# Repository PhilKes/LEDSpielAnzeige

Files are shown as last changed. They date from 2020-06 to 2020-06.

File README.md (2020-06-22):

# LEDSpielAnzeige - Controller for LED Scoreboard
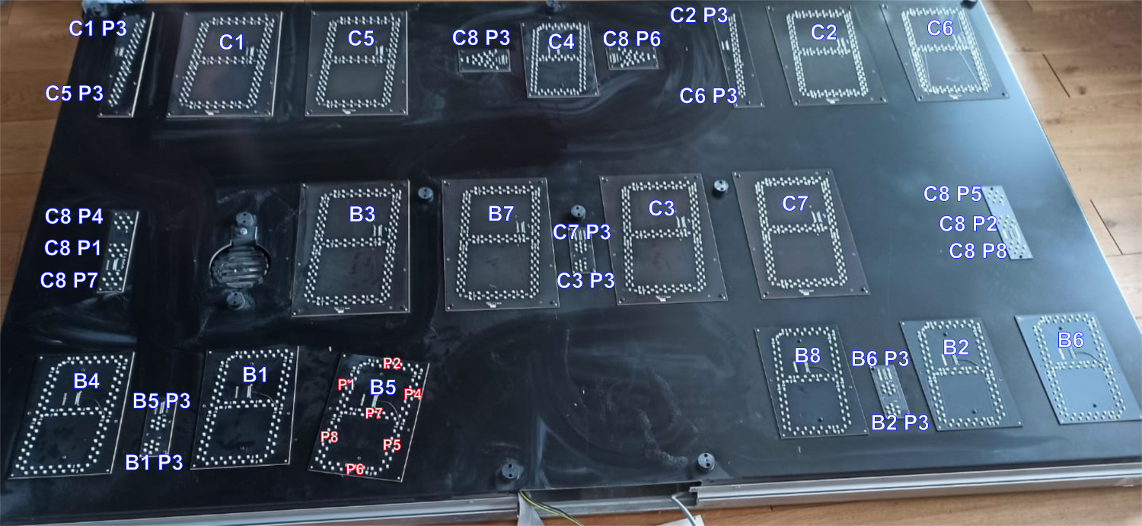
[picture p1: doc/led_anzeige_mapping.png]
LED Display
 
 
 ### Display
 * 2 x 8 7-Segment Displays
 * Eacg Segment 7 LEDs in Series (Vfor=1.9V)
 * Center Segments 8 LEDs in Series
 * All Anodes (+) of the same Segments connected (all SegA,...) (Data)
 * LEDs of a single 7-Segment Display have a common Cathode (-) (Address)
 * DecimalPoint connections for ":",">","|",...
 
 ### Connections
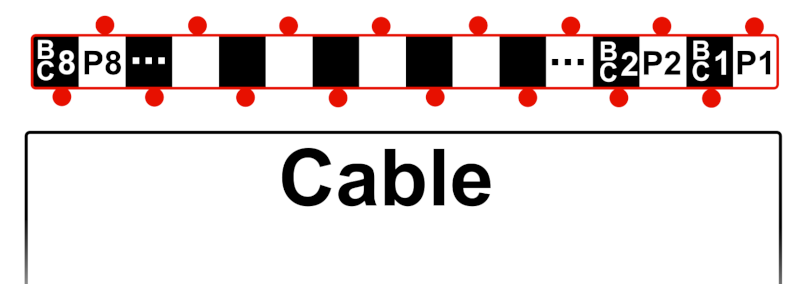
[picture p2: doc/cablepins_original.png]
2x8 Cable Pinout
  
 * 2x 16Pin Cable connections
 * 8 Pin Address (only a single Bit "1" at a time)
 * 8 Pin Data (7-Segments)
 * Addresses are multiplexed
 
 ### Schematic
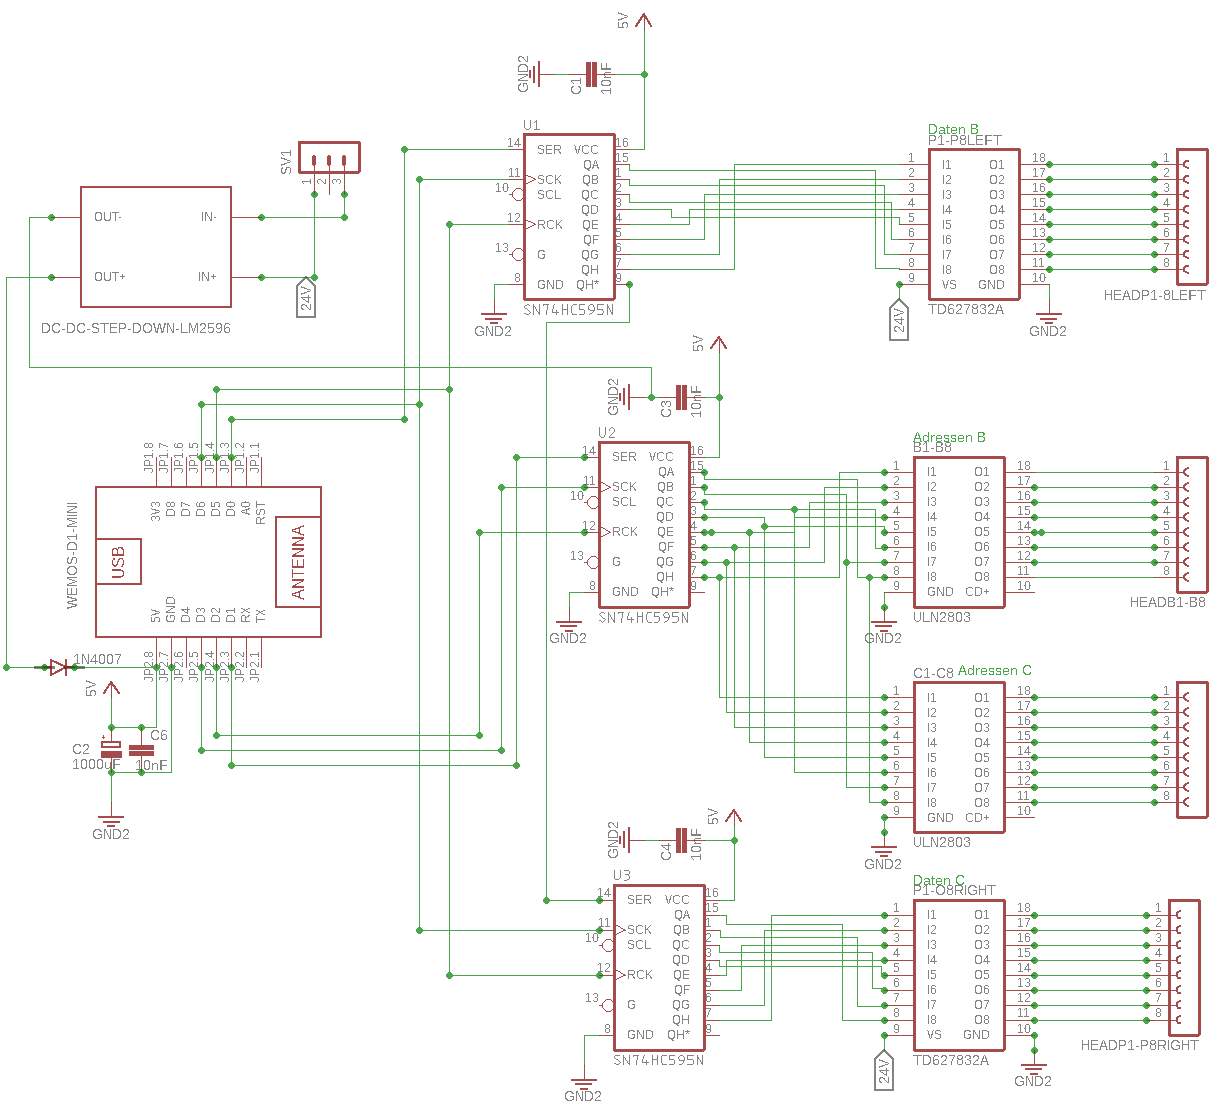
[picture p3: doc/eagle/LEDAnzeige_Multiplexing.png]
Display_Schaltplan
 
  ---
 ### Board
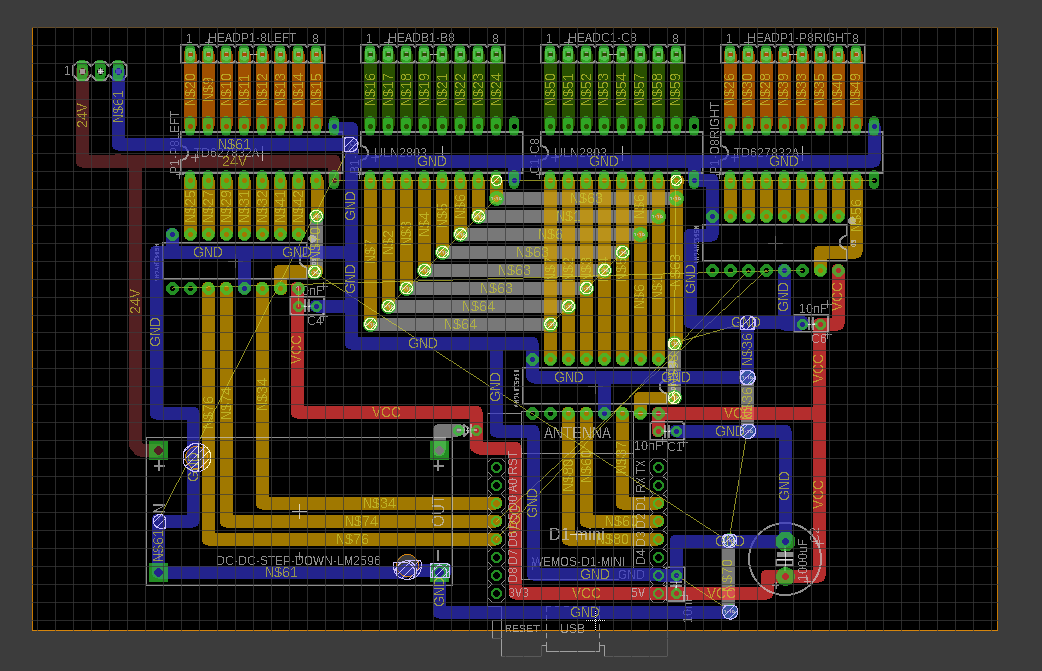
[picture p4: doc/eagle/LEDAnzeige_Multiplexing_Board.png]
Display_Board
 
 [Mirrored Image for Soldering](./doc/eagle/LEDAnzeige_Multiplexing_Board_mirror.png)
 ---
 #### Parts
  * [LM2596 Step-Down DC Buck Converter](https://www.reichelt.de/schaltregler-step-down-adj-3a-4-75-40vi-to220-5-lm2596tvadj-p255435.html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)
  * [IC Sockel 14/16pin](https://www.reichelt.de/ic-sockel-16-polig-doppelter-federkontakt-gs-16-p8208.html?&nbc=1)
  * [Perboard 16x10cm](https://www.reichelt.de/lochrasterplatine-hartpapier-160x100mm-h25pr160-p8272.html?&nbc=1)
  * [WeMos D1 mini](https://www.ebay.de/itm/D1Mini-ESP8266-Modul-Mikrokontroller-Board-WLAN-Wifi-Nodemcu-Wemos-Arduino/164007576934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)
  * [DCAdapter 24V](https://www.reichelt.de/steckernetzteil-25-w-24-v-1-04-a-mw-gst25e24-p171101.html?&nbc=1)
#### Drivers
 * [UDN 2981(=_TD62783AP_)  Source Driver](https://www.reichelt.de/leistungstreiber-8-kanal-dil-18-udn-2981-p22008.html?&trstct=pos_0&nbc=1)
 * [ULN2803 NPN Darlington Arrays](https://www.reichelt.de/eight-darlington-arrays-dil-18-uln-2803a-p22085.html?&trstct=pos_0&nbc=1)
 * [74HC595 Shift Register](https://www.reichelt.de/shift-register-3-state-ausgang-2-6-v-dil-16-74hc-595-p3269.html?&trstct=pos_0&nbc=1)
 ---
 
 # Code
 
 ### Wemos Arduino Sketch
 * **Multiplexing** both Addressbusses (**Common Cathodes**) (_ULN2803s_ "B1-B8"+"C1-C8") with 1x _74HC595_ ("U2") output
 * Loading **7-Segment Data** (**Anodes**) for every Display concurrent to multiplexing with 2x _74HC595_ ("U1"+"U3")
 * Switch modes on **WiFi** commands
 
 ### React Web App
 * **WebServer** for User Interface
 * Sending Commands over WiFi
 * [ESP8266-React Framework](https://github.com/rjwats/esp8266-react)
 ---
 ### Links
 * [ULN2803 Function](https://www.conrad.de/de/ratgeber/handwerk-industrie-wiki/elektronik-bauteile/uln2803.html#anschluss)
 * [Arduino Forum Thread](https://forum.arduino.cc/index.php?topic=688158.0)

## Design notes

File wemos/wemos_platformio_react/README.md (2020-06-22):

# Wemos_react_platformio

## Getting Started
 #### Settings
 1. Make sure in [/factory_settings](./factory_settings.ini) WiFi Access Point is enabled:
`-D FACTORY_AP_PROVISION_MODE=AP_MODE_ALWAYS`
 2. [Build & Upload](#building--uploading) the Project
 3. Connect to *ESP8266-React* WiFi network via Phone

#### WiFi
 1. WiFi Connection-> Scan Networks -> Connect to local WiFi
 2. Preferably set a Static IP for Local Development (see [.env.development](./interface/.env.development))

 #### NTP
1. Network Time -> NTP Settings
2. Select correct Time Zone -> Save
 
### Building & Uploading
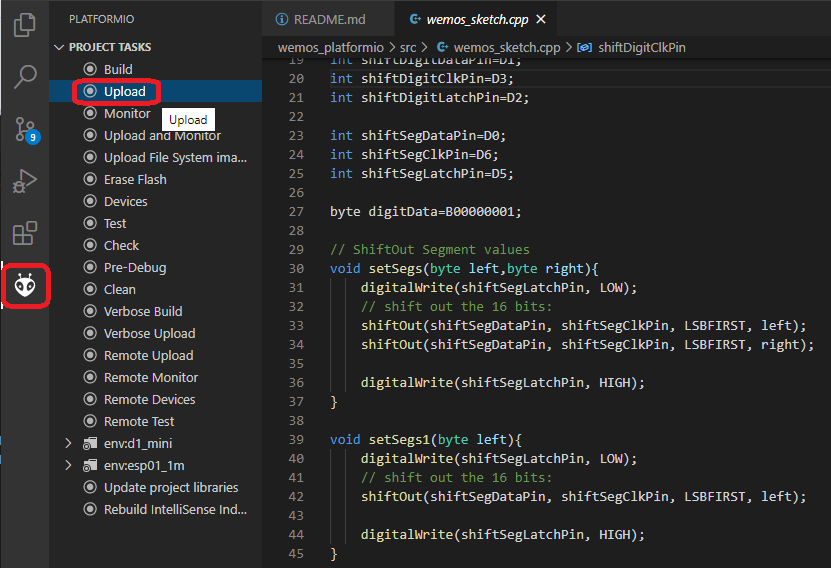
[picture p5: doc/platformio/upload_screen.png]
Build+Upload


To Enable/Disable OTA Upload [platformio.ini](./platformio.ini)):

`; Uncomment & modify the lines below in order to configure OTA updates
;upload_protocol=espota
;upload_port = 192.168.178.55
;upload_auth=esp-react`

#### Debugging
in [main.cpp](./src/main.cpp) and [wemos_sketch.h](./src/wemos/wemos_sketch.h):

`#define DEBUG true`

to enable Debugging via Serial-Connection (USB + `Serial.print`)

Default Environment: d1_mini

# Code
## Wemos Backend Sketch
[main.cpp](./src/main.cpp)

Runs ESP8266 React Web Server + Wemos Sketch Loop

[wemos_sketch.h](./src/wemos_sketch.h):

`wemosLoop(digitsLeft,digitsRight,ntpStatus)`

* Executes Multiplex with current digits as Segment Values (`digitsLeft` & `digitsRight` changed by HTTP Requests from WebServer)
* `ntpStatus` can be used to get current Time (`setTime(ntpStatus->getTime())`)

[LEDScoreboardService](./src/LEDScoreboardService.h)

* Receives state (`digitsLeft` & `digitsRight`) updates from frontend HTTP requests via ArduinoJson Objects
* Accesses `NTPStatus` to get current LocalTime

---

## Wemos React Frontend App

[LEDScoreboardRestController.tsx](./interface/src/project/LEDScoreboardRestController.tsx)

Subpage for sending HTTP Requests to control `digitsLeft` & `digitsRight`

`LEDScoreboardRestControllerForm` (React component for Inputs to change digit Values / modes)

Given component `props`:
* `data` : corresponds to [LEDScoreboardState in backend](./src/LEDScoreboardService.h)
* `loadData()` : Fetches state from backend
* `handleValueChange(String propertyKey)` : Sets value of given property
* `saveData()` : Sends updated state to backend

---

#### Libraries Used

* [React](https://reactjs.org/)
* [Material-UI](https://material-ui.com/)
* [notistack](https://github.com/iamhosseindhv/notistack)
* [ArduinoJson](https://github.com/bblanchon/ArduinoJson)
* [ESPAsyncWebServer](https://github.com/me-no-dev/ESPAsyncWebServer)
* [AsyncMqttClient](https://github.com/marvinroger/async-mqtt-client)

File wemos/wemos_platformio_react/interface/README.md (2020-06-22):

# LED Scoreboard - ESP8266 React

[Main Project Page .tsx](./src/project/LEDScoreboard)

## LED Scoreboard Project Routes:
_LEDScoreboard.tsx_:

    <Switch>
      <AuthenticatedRoute exact path={`/${PROJECT_PATH}/rest`} component={LightStateRestController} />
      <AuthenticatedRoute exact path={`/${PROJECT_PATH}/socket`} component={LightStateWebSocketController} />
      <Redirect to={`/${PROJECT_PATH}/rest`} />
    </Switch>

## REST Controller
HTTP Request to control WeMos

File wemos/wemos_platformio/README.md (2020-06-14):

## Wemos PlatformIO Project

### Code

Main Code in [/src/wemos_sketch.cpp](./src/wemos_sketch.cpp)

Different Modes/Animations in [/src/modes.h](./src/modes.h)

### Building & Uploading
Build+Upload

Default Environment: d1_mini (see [platformio.ini](./platformio.ini))

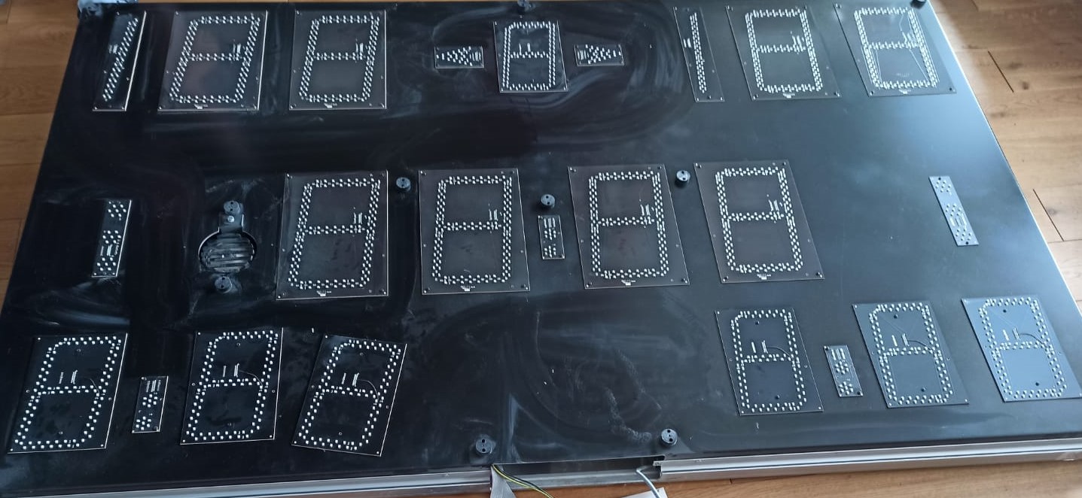
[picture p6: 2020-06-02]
doc/led_anzeige_bild.jpg

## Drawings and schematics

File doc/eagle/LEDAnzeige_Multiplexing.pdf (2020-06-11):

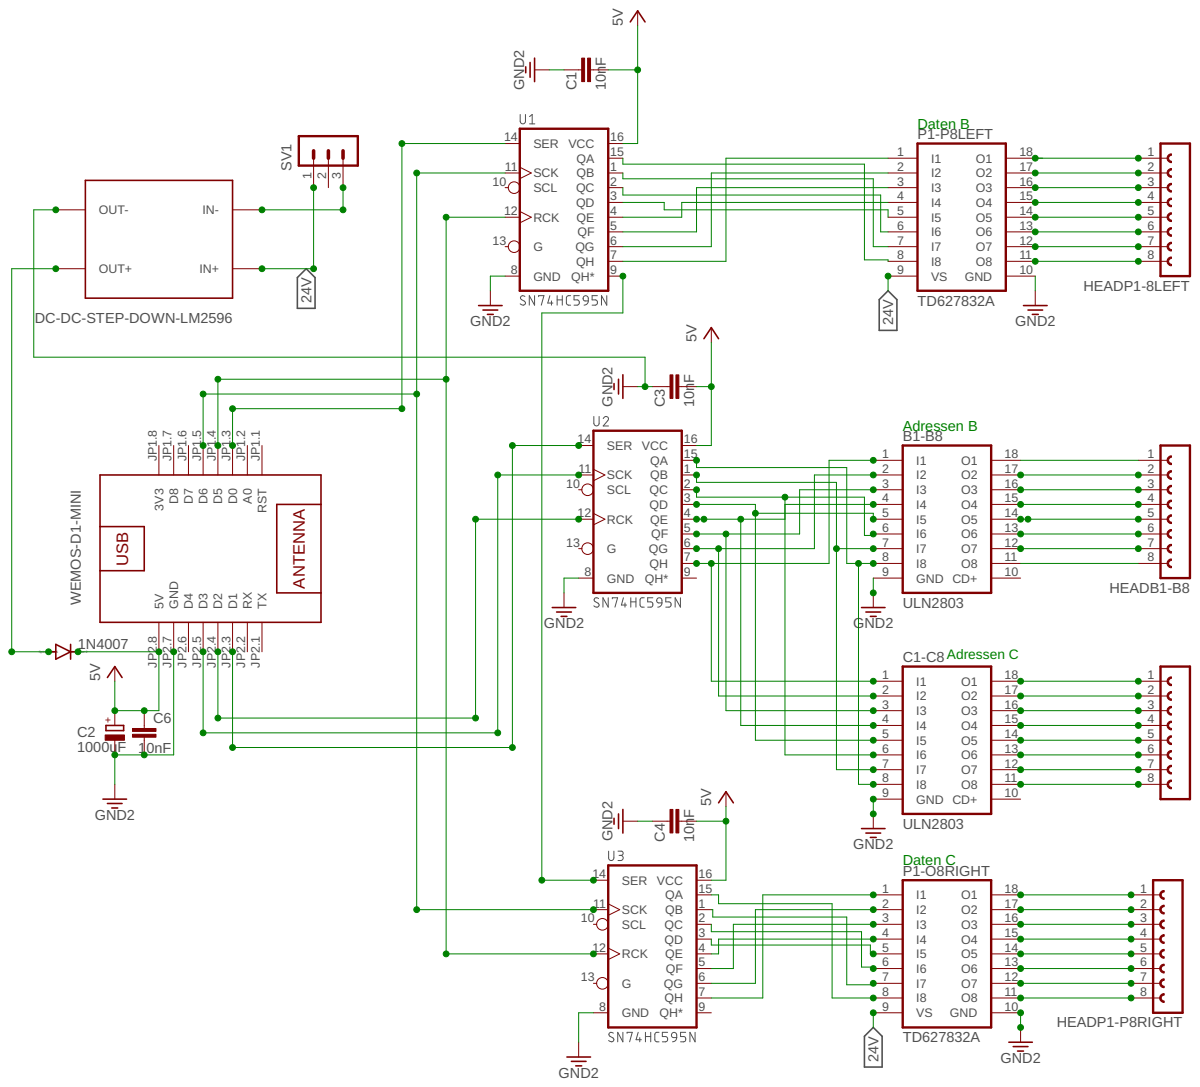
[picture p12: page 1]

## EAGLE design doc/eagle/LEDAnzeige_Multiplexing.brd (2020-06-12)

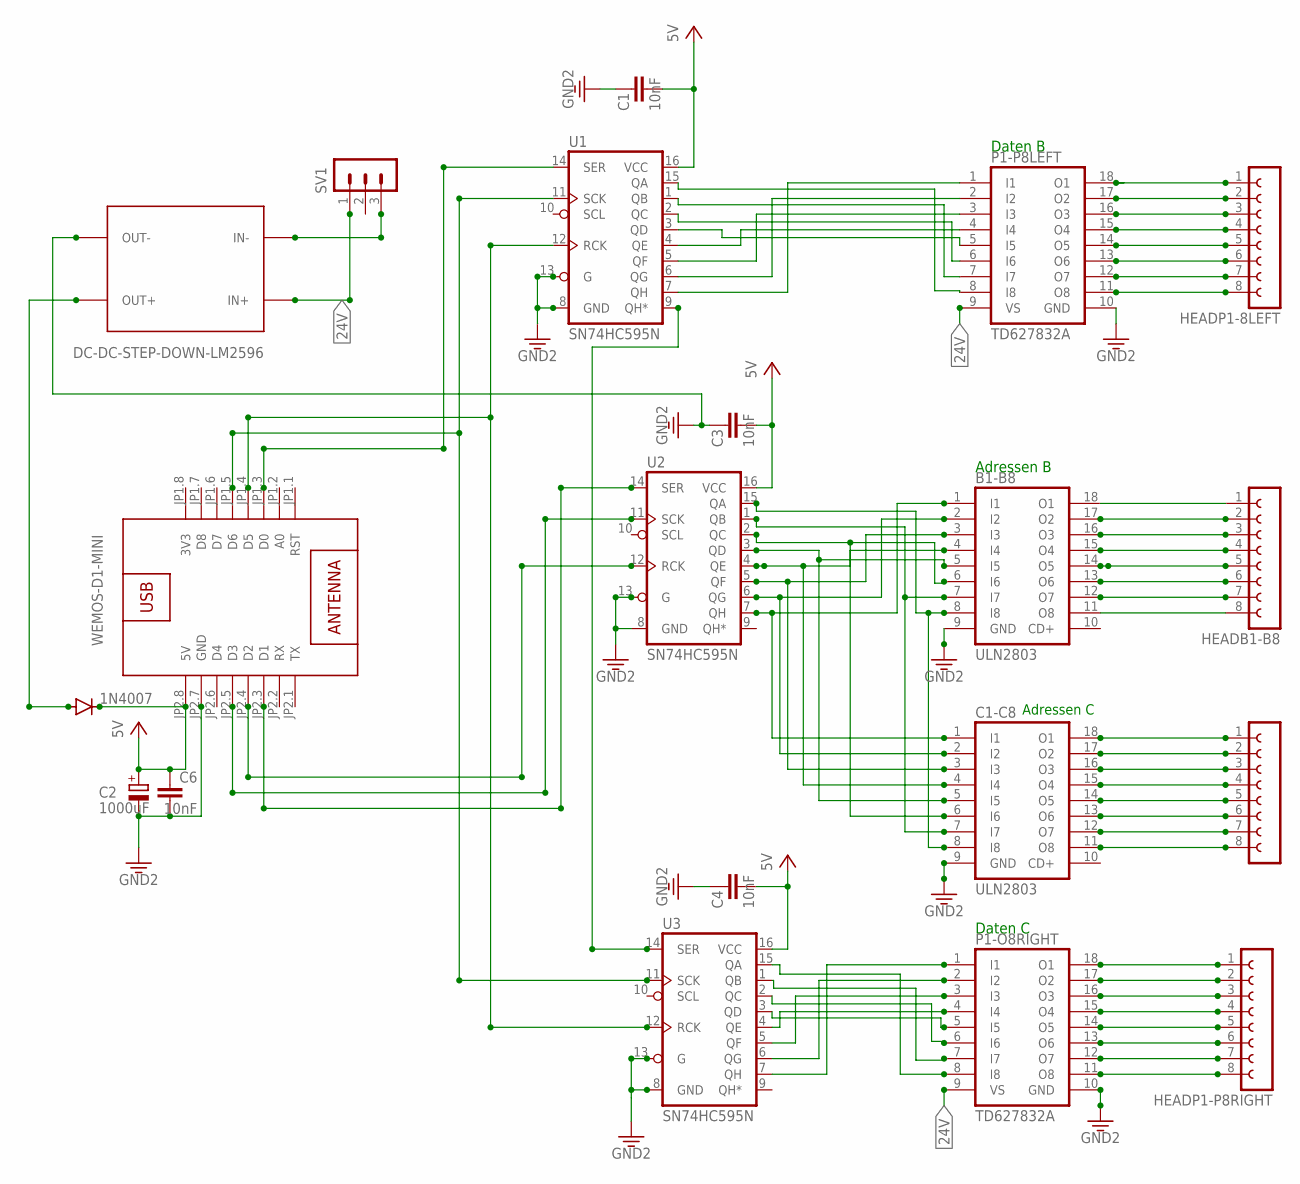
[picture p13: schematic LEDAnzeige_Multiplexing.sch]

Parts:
1N4007: DIODE-D-2.5; D-2.5
B1-B8: ULN2803; DIL18
C1, C3, C4, C6: 10nF; C025-025X050
C1-C8: ULN2803; DIL18
C2: 1000uF; E5-10,5
HEADB1-B8: FE08-1; FE08
HEADC1-C8: FE08-1; FE08
HEADP1-8LEFT, HEADP1-P8RIGHT: FE08-1; FE08
P1-O8RIGHT, P1-P8LEFT: TD627832A; DIL18
SV1: MA03-1
U1, U2, U3: SN74HC595N; DIP16
U$1: WEMOS-D1-MINI
U$2: DC-DC-STEP-DOWN-LM2596

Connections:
3V3: U$1.JP1.8 (3V3)
24V: P1-O8RIGHT.9 (VS), P1-P8LEFT.9 (VS), SV1.1, U$2.IN+
GND: B1-B8.9 (GND), C1.1, C1-C8.9 (GND), C2.-, C3.1, C4.1, C6.2, P1-O8RIGHT.10 (GND), P1-P8LEFT.10 (GND), U1.8 (GND), U1.13 (G), U2.8 (GND), U2.13 (G), U3.8 (GND), U3.13 (G), U$1.JP2.7 (GND), U$2.OUT-
unnamed: B1-B8.7 (I7), C1-C8.7 (I7), U2.1 (QB)
unnamed: B1-B8.2 (I2), C1-C8.2 (I2), U2.6 (QG)
unnamed: B1-B8.3 (I3), C1-C8.3 (I3), U2.5 (QF)
unnamed: B1-B8.4 (I4), C1-C8.4 (I4), U2.4 (QE)
unnamed: B1-B8.5 (I5), C1-C8.5 (I5), U2.3 (QD)
unnamed: B1-B8.6 (I6), C1-C8.6 (I6), U2.2 (QC)
unnamed: B1-B8.1 (I1), C1-C8.1 (I1), U2.7 (QH)
unnamed: B1-B8.8 (I8), C1-C8.8 (I8), U2.15 (QA)
unnamed: HEADP1-8LEFT.2, P1-P8LEFT.17 (O2)
unnamed: HEADP1-8LEFT.3, P1-P8LEFT.16 (O3)
unnamed: HEADP1-8LEFT.4, P1-P8LEFT.15 (O4)
unnamed: HEADP1-8LEFT.5, P1-P8LEFT.14 (O5)
unnamed: HEADP1-8LEFT.6, P1-P8LEFT.13 (O6)
unnamed: HEADP1-8LEFT.7, P1-P8LEFT.12 (O7)
unnamed: HEADP1-8LEFT.8, P1-P8LEFT.11 (O8)
unnamed: B1-B8.18 (O1), HEADB1-B8.1
unnamed: B1-B8.17 (O2), HEADB1-B8.2
unnamed: B1-B8.16 (O3), HEADB1-B8.3
unnamed: B1-B8.15 (O4), HEADB1-B8.4
unnamed: HEADP1-8LEFT.1, P1-P8LEFT.18 (O1)
unnamed: B1-B8.14 (O5), HEADB1-B8.5
unnamed: B1-B8.13 (O6), HEADB1-B8.6
unnamed: B1-B8.12 (O7), HEADB1-B8.7
unnamed: B1-B8.11 (O8), HEADB1-B8.8
unnamed: P1-P8LEFT.1 (I1), U1.7 (QH)
unnamed: HEADP1-P8RIGHT.1, P1-O8RIGHT.18 (O1)
unnamed: P1-P8LEFT.2 (I2), U1.6 (QG)
unnamed: HEADP1-P8RIGHT.3, P1-O8RIGHT.16 (O3)
unnamed: P1-P8LEFT.3 (I3), U1.5 (QF)
unnamed: HEADP1-P8RIGHT.2, P1-O8RIGHT.17 (O2)
unnamed: P1-P8LEFT.4 (I4), U1.4 (QE)
unnamed: P1-P8LEFT.5 (I5), U1.3 (QD)
unnamed: HEADP1-P8RIGHT.5, P1-O8RIGHT.14 (O5)
unnamed: U1.14 (SER), U$1.JP1.3 (D0)
unnamed: HEADP1-P8RIGHT.6, P1-O8RIGHT.13 (O6)
unnamed: U2.14 (SER), U$1.JP2.3 (D1)
unnamed: HEADP1-P8RIGHT.4, P1-O8RIGHT.15 (O4)
unnamed: HEADP1-P8RIGHT.7, P1-O8RIGHT.12 (O7)
unnamed: P1-P8LEFT.6 (I6), U1.2 (QC)
unnamed: P1-P8LEFT.7 (I7), U1.1 (QB)
unnamed: P1-P8LEFT.8 (I8), U1.15 (QA)
unnamed: P1-O8RIGHT.2 (I2), U3.6 (QG)
unnamed: P1-O8RIGHT.3 (I3), U3.5 (QF)
unnamed: P1-O8RIGHT.4 (I4), U3.4 (QE)
unnamed: P1-O8RIGHT.5 (I5), U3.3 (QD)
unnamed: P1-O8RIGHT.6 (I6), U3.2 (QC)
unnamed: HEADP1-P8RIGHT.8, P1-O8RIGHT.11 (O8)
unnamed: C1-C8.18 (O1), HEADC1-C8.1
unnamed: C1-C8.17 (O2), HEADC1-C8.2
unnamed: C1-C8.16 (O3), HEADC1-C8.3
unnamed: C1-C8.15 (O4), HEADC1-C8.4
unnamed: C1-C8.14 (O5), HEADC1-C8.5
unnamed: P1-O8RIGHT.7 (I7), U3.1 (QB)
unnamed: P1-O8RIGHT.8 (I8), U3.15 (QA)
unnamed: C1-C8.13 (O6), HEADC1-C8.6
unnamed: C1-C8.12 (O7), HEADC1-C8.7
unnamed: C1-C8.11 (O8), HEADC1-C8.8
unnamed: U2.12 (RCK), U$1.JP2.4 (D2)
unnamed: SV1.3, U$2.IN-
unnamed: 1N4007.A, U$2.OUT+
unnamed: P1-O8RIGHT.1 (I1), U3.7 (QH)
unnamed: U1.12 (RCK), U3.12 (RCK), U$1.JP1.4 (D5)
unnamed: U1.11 (SCK), U3.11 (SCK), U$1.JP1.5 (D6)
unnamed: U2.11 (SCK), U$1.JP2.5 (D3)
unnamed: U1.9 (QH*), U3.14 (SER)
VCC: 1N4007.C, C1.2, C2.+, C3.2, C4.2, C6.1, U1.16 (VCC), U2.16 (VCC), U3.16 (VCC), U$1.JP2.8 (5V)

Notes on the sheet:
Daten B
Daten C
Adressen B
Adressen C

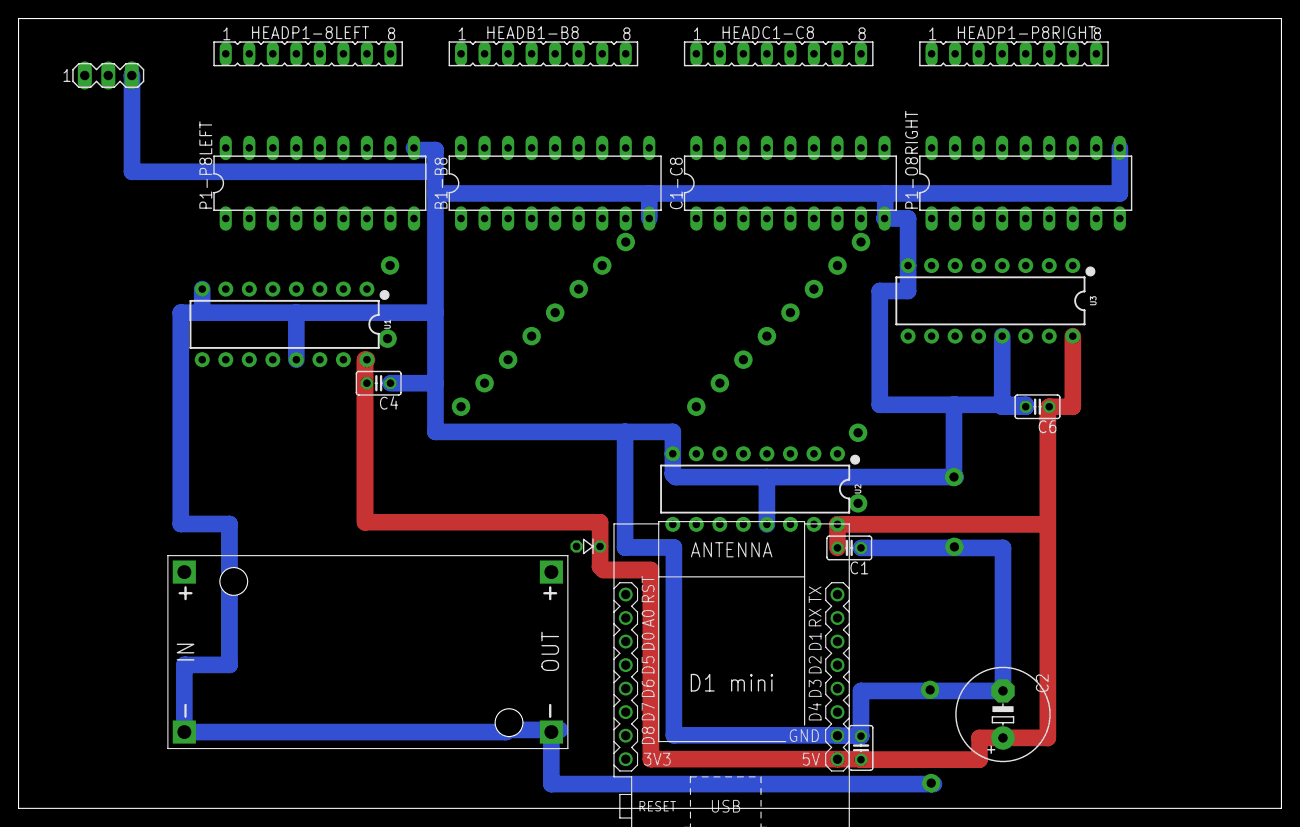
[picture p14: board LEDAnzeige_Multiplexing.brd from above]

Board: 8 copper layers, 136.3 x 85.3 mm, 20 parts (0 on the bottom side), 68 nets.

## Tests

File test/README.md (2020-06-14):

### Test Sketches for WeMos D1 mini
* [Wemos Numbers Loop Test Sketch](./wemos_sketch/wemos_sketch.ino)
* [Wemos Shift Register Serial Test Sketch](./wemos_serial_sketch/wemos_serial_sketch.ino)

**Note**: IDE Board Setting: _LOLIN(WEMOS) D1 R2 & mini_

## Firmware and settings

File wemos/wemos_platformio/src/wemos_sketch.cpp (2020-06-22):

#include <modes.h>
#include <ESP8266WiFi.h>
#include <ESP8266mDNS.h>
#include <WiFiUdp.h>
#include <ArduinoOTA.h>
//#include <wifi_settings.h>
#include <ESP8266WiFiMulti.h>
#include <time.h>


//DEBUG true, for USB debugging
#define DEBUG false
//OTA_ENABLED true, for Over The Air Updates (WiFi sketch upload)
#define OTA_ENABLED true

//init of the command interface as simple static html site
ESP8266WiFiMulti WiFiMulti;
WiFiUDP ntpUDP;
WiFiServer cmd_server(port);

//string to get commands from cmd_client
String readString = String(100);

int shiftDigitDataPin=D1;
int shiftDigitClkPin=D3;
int shiftDigitLatchPin=D2;

int shiftSegDataPin=D0;
int shiftSegClkPin=D6;
int shiftSegLatchPin=D5;

int mode=0;


inline void flashLEDBuiltIn(){
  digitalWrite(LED_BUILTIN, HIGH);
  delay(500);
  digitalWrite(LED_BUILTIN, LOW);
  delay(500);
  digitalWrite(LED_BUILTIN, HIGH);
} 

// ShiftOut Segment values
inline void setSegs(byte left,byte right)
{
    digitalWrite(shiftSegLatchPin, LOW);
    // shift out the 16 bits:
    shiftOut(shiftSegDataPin, shiftSegClkPin, LSBFIRST, right);  
    shiftOut(shiftSegDataPin, shiftSegClkPin, LSBFIRST, left);  
  
    digitalWrite(shiftSegLatchPin, HIGH);
}

//set the new set of diigts to display the numbers in the multiplex loop 
inline void setDigits(byte value)
{
    digitalWrite(shiftDigitLatchPin, LOW);
    shiftOut(shiftDigitDataPin, shiftDigitClkPin, LSBFIRST, value);
    digitalWrite(shiftDigitLatchPin, HIGH);
}

//Init all Digits to 1st On, all other off
inline void initDigits()
{
  setDigits(0);
}

//Init all Segments to on
inline void initSegs()
{
  setSegs(0,0);
}

volatile byte digitData=B10000000;
//Index of current active Display (starting with 1)
volatile byte displayIdx=0;

//Turns all Segs off, shift the Digits "1" to the left, if last Digit reached, reset to first Digit
//returns true if last Digit was displayed
inline void nextDigit()
{
    if(digitData==B10000000)
    {
      digitData=B00000001;
      displayIdx=0;
    }
    else
    {
      digitData=digitData<<1;
      displayIdx++;
    }

    setSegs(0,0); //Turn all Segments off
    setDigits(digitData);
}

/* main multiplex Loop */
inline void multiplexLoop(int multiDel)
 {
   do{
      nextDigit();
      if (dimBrightness != 10) {
        setSegs(0,0); //turn off digits for a part of the multiplex time to dim the brightness
        delayMicroseconds(dimDelay);
      }
      setSegs(digitsLeft[displayIdx],digitsRight[displayIdx]);
      delayMicroseconds(multiDel - dimDelay);
   }while(digitData!=B10000000);
   multiplexCount++;
   if (multiplexCount >180000){
     multiplexCount = 0;
   }
 }

inline void allOn() {
    for (byte i = 0; i < 8; i++)
    {
      digitsLeft[i]=255;
      digitsRight[i]=255;
    }
}

//the static html on ip: 192.168.178.55 or per local dns led.intern
inline void showWebInterface() {
    WiFiClient cmd_client = cmd_server.available();
    if (cmd_client){
    while(cmd_client.connected())
    {
      char c = cmd_client.read();
      if (readString.length() < 100) {
        readString = readString + c; 
        }
      if (c == '\n') {  
        if(readString.indexOf("3=Up") > -1) {
          scoreHome = scoreHome +1;
        }
        if(readString.indexOf("3=Down") > -1){
          scoreHome = scoreHome -1;
        }
        if(readString.indexOf("4=Up") > -1) {
          scoreGuest = scoreGuest +1;
        }
        if(readString.indexOf("4=Down") > -1){
          scoreGuest = scoreGuest -1;
        }
        if(readString.indexOf("all=Scores+On+or+Off") > -1){
          if (scoreOnOff) {
            scoreOnOff = false;
          } else {
            scoreOnOff = true;
            scoreHome = 0;
            scoreGuest = 0;
          }
        }
        if(readString.indexOf("all=Display+Seconds+On+or+Off") > -1){
          if (dispSeconds){
            dispSeconds = false;
          } else {
            dispSeconds = true;
          }
        }
        if(readString.indexOf("all=Display+Temperature+On+or+Off") > -1){
          if (dispTemp){
            dispTemp = false;
          } else {
            dispTemp = true;
            timeWeather = 0;
            getWeather();
          }
        }      
        if (readString.indexOf("quantityHome") > -1){
          int index = readString.indexOf("quantityHome");
          String num = readString.substring(index+13);
          scoreHome = scoreHome + num.toInt();
        }
        if (readString.indexOf("quantityGuest") > -1){
          int index = readString.indexOf("quantityGuest");
          String num = readString.substring(index+14);
          scoreGuest = scoreGuest + num.toInt();
        }
        if (readString.indexOf("brightness") > -1){
          int index = readString.indexOf("brightness");
          String num = readString.substring(index+11);
          dimBrightness = num.toInt();
          dimDelay = multiplexDelay - ((dimBrightness) * multiplexDelay/10) - 1;
        } 
        if(readString.indexOf("all=Set") > -1){
          
        }
        if(readString.indexOf("all=Kabu+mode+On+or+Off") > -1){
          if (kabuMode){
            kabuMode = false;
            setNames = false;
            player1 = "Player 1";
            player2 = "Player 2";
            player3 = "Player 3";
            player4 = "Player 4";
          } else {
            kabuMode = true;
            dispSeconds = false;
            dispTemp = false;
            scoreOnOff = false;
            playerNamesSet = 0;
            kabuScore1 = 0;
            kabuScore2 = 0;
            kabuScore3 = 0;
            kabuScore4 = 0;
          }
        } 
        if (kabuMode) {    
          if (readString.indexOf("p1Points") > -1){
            int index = readString.indexOf("p1Points");
            String num = readString.substring(index+9);
            kabuScore1 = kabuScore1 + num.toInt();
          }
          if (readString.indexOf("p2Points") > -1){
            int index = readString.indexOf("p2Points");
            String num = readString.substring(index+9);
            kabuScore2 = kabuScore2 + num.toInt();
          }
          if (readString.indexOf("p3Points") > -1){
            int index = readString.indexOf("p3Points");
            String num = readString.substring(index+9);
            kabuScore3 = kabuScore3 + num.toInt();
          }
          if (readString.indexOf("p4Points") > -1){
            int index = readString.indexOf("p4Points");
            String num = readString.substring(index+9);
            kabuScore4 = kabuScore4 + num.toInt();
          }

          if (readString.indexOf("p1Name") > -1){
            int index = readString.indexOf("p1Name");
            player1 = readString.substring(index+7, readString.indexOf("HTTP"));
            playerNamesSet++;
          }
          if (readString.indexOf("p2Name") > -1){
            int index = readString.indexOf("p2Name");
            player2 = readString.substring(index+7, readString.indexOf("HTTP"));
            playerNamesSet++;
          }
          if (readString.indexOf("p3Name") > -1){
            int index = readString.indexOf("p3Name");
            player3 = readString.substring(index+7, readString.indexOf("HTTP"));
            playerNamesSet++;
          }
          if (readString.indexOf("p4Name") > -1){
            int index = readString.indexOf("p4Name");
            player4= readString.substring(index+7, readString.indexOf("HTTP"));
            setNames=true;
            playerNamesSet = 0;
          }
        }



        cmd_client.println("HTTP/1.1 200 OK");
        cmd_client.println("Content-Type: text/html");
        cmd_client.println();
        cmd_client.print("<html><head>");
        cmd_client.print("<title>Arduino Webserver Anzeige</title>");
        cmd_client.println("</head>");
        cmd_client.print("<body bgcolor='#444444'>");
        //---Überschrift---
        cmd_client.println("<br><hr />");
        cmd_client.println("<h1><div align='left'><font color='#DF7401'>Anzeigetafel Arduino</font color></div></h1>");
        cmd_client.println("<hr /><br>");
        cmd_client.println("<div align='left'><font face='Verdana' color='#FFFFFF'>Set the level of Brightness </font></div>");
        cmd_client.println("<td align='center' bgcolor='#222222'><form method=get><input type=range name=brightness min='0' max='10' value='"+String(dimBrightness)+"' onchange='this.form.submit()' step='1'></form></td>"); 
        cmd_client.println("<br>");  
        cmd_client.println("<form method=get><input type=submit name=all value='Scores On or Off'></form>");
        cmd_client.println("<br>");   
        if (scoreOnOff){     
          cmd_client.println("<div align='left'><font face='Verdana' color='#FFFFFF'>Scores:</font></div>");
          cmd_client.println("<table border='1' width='500' cellpadding='5'>");
          cmd_client.println("<tr bgColor='#222222'>");
          cmd_client.println("<td bgcolor='#222222'><font face='Verdana' color='#CFCFCF' size='2'>Home: "+String(scoreHome)+"<br></font></td>");
          cmd_client.println("<td align='center' bgcolor='#222222'><form method=get><input type=submit name=3 value='Up'></form></td>");
          cmd_client.println("<td align='center' bgcolor='#222222'><form method=get><input type=submit name=3 value='Down'></form></td>");
          cmd_client.println("<td align='center' bgcolor='#222222'><form method=get><input type=number name=quantityHome min='-10' max ='100'></form></td>");      
          cmd_client.println("</tr>");
          cmd_client.println("<tr bgColor='#222222'>");
          cmd_client.println("<td bgcolor='#222222'><font face='Verdana' color='#CFCFCF' size='2'>Guest: "+String(scoreGuest)+"<br></font></td>");
          cmd_client.println("<td align='center' bgcolor='#222222'><form method=get><input type=submit name=4 value='Up'></form></td>");
          cmd_client.println("<td align='center' bgcolor='#222222'><form method=get><input type=submit name=4 value='Down'></form></td>");
          cmd_client.println("<td align='center' bgcolor='#222222'><form method=get><input type=number name=quantityGuest min='-10' max ='100'></form></td>"); 
          cmd_client.println("</tr>");
          cmd_client.println("</tr>");
          cmd_client.println("</table>");
        }
        cmd_client.println("<br>");
        cmd_client.println("<form method=get><input type=submit name=all value='Kabu mode On or Off'></form>");
        cmd_client.println("<br>");
        if (kabuMode){
          if (setNames){
            cmd_client.println("<div align='left'><font face='Verdana' color='#FFFFFF'>Kabu scores:</font></div>");
            cmd_client.println("<br>");
            cmd_client.println("<table border='1' width='500' cellpadding='5'>");
            cmd_client.println("<tr bgColor='#222222'>");
            cmd_client.println("<td bgcolor='#222222'><font face='Verdana' color='#CFCFCF' size='2'>"+player1+": "+String(kabuScore1)+"<br></font></td>");
            cmd_client.println("<td align='center' bgcolor='#222222'><form method=get><input type=number name=p1Points min='-2' max ='100'></form></td>");    

            cmd_client.println("</tr>");
            cmd_client.println("<tr bgColor='#222222'>");
            cmd_client.println("<td bgcolor='#222222'><font face='Verdana' color='#CFCFCF' size='2'>"+player2+": "+String(kabuScore2)+"<br></font></td>");
            cmd_client.println("<td align='center' bgcolor='#222222'><form method=get><input type=number name=p2Points min='-2' max ='100'></form></td>"); 

            cmd_client.println("</tr>");
            cmd_client.println("<tr bgColor='#222222'>");
            cmd_client.println("<td bgcolor='#222222'><font face='Verdana' color='#CFCFCF' size='2'>"+player3+": "+String(kabuScore3)+"<br></font></td>");
            cmd_client.println("<td align='center' bgcolor='#222222'><form method=get><input type=number name=p3Points min='-2' max ='100'></form></td>"); 

            cmd_client.println("</tr>");
            cmd_client.println("<tr bgColor='#222222'>");
            cmd_client.println("<td bgcolor='#222222'><font face='Verdana' color='#CFCFCF' size='2'>"+player4+": "+String(kabuScore4)+"<br></font></td>");
            cmd_client.println("<td align='center' bgcolor='#222222'><form method=get><input type=number name=p4Points min='-2' max ='100'></form></td>"); 
            cmd_client.println("</table>");
          } else {
            if (playerNamesSet == 0) {
              cmd_client.println("<div align='left'><font face='Verdana' color='#FFFFFF'>Please enter Player name:</font></div>");
              cmd_client.println("<br>");
              cmd_client.println("<table border='1' width='500' cellpadding='5'>");
              cmd_client.println("<tr bgColor='#222222'>");
              cmd_client.println("<td bgcolor='#222222'><font face='Verdana' color='#CFCFCF' size='2'>"+player1+" <br></font></td>");
              cmd_client.println("<td align='center' bgcolor='#222222'><form method=get><input type=text name=p1Name ></form></td>");  
              cmd_client.println("</table>");  
            } if (playerNamesSet ==1){
              cmd_client.println("<div align='left'><font face='Verdana' color='#FFFFFF'>Please enter Player name:</font></div>");
              cmd_client.println("<br>");
              cmd_client.println("<table border='1' width='500' cellpadding='5'>");
              cmd_client.println("<tr bgColor='#222222'>");
              cmd_client.println("<td bgcolor='#222222'><font face='Verdana' color='#CFCFCF' size='2'>"+player2+"<br></font></td>");
              cmd_client.println("<td align='center' bgcolor='#222222'><form method=get><input type=text name=p2Name ></form></td>"); 
              cmd_client.println("</table>");
            } if (playerNamesSet ==2){
              cmd_client.println("<div align='left'><font face='Verdana' color='#FFFFFF'>Please enter Player name:</font></div>");
              cmd_client.println("<br>");
              cmd_client.println("<table border='1' width='500' cellpadding='5'>");
              cmd_client.println("<tr bgColor='#222222'>");
              cmd_client.println("<td bgcolor='#222222'><font face='Verdana' color='#CFCFCF' size='2'>"+player3+"<br></font></td>");
              cmd_client.println("<td align='center' bgcolor='#222222'><form method=get><input type=text name=p3Name ></form></td>"); 
              cmd_client.println("</table>");
            } if (playerNamesSet ==3){
              cmd_client.println("<div align='left'><font face='Verdana' color='#FFFFFF'>Please enter Player name:</font></div>");
              cmd_client.println("<br>");
              cmd_client.println("<table border='1' width='500' cellpadding='5'>");
              cmd_client.println("<tr bgColor='#222222'>");
              cmd_client.println("<td bgcolor='#222222'><font face='Verdana' color='#CFCFCF' size='2'>"+player4+"<br></font></td>");
              cmd_client.println("<td align='center' bgcolor='#222222'><form method=get><input type=text name=p4Name ></form></td>"); 
              cmd_client.println("</table>");
            }
          }
        }
        cmd_client.println("<br>");
        cmd_client.println("<form method=get><input type=submit name=all value='Display Seconds On or Off'></form>");
        cmd_client.println("<form method=get><input type=submit name=all value='Display Temperature On or Off'></form>");
        cmd_client.println("<br>");

        cmd_client.println("</body></html>");
        readString="";

        cmd_client.stop();
      } 
      multiplexLoop(multiplexDelay);
    }}
}

// Set pinModes + init Digits&Segments
 void setup() 
 {

  pinMode(LED_BUILTIN, OUTPUT);

  pinMode(shiftDigitDataPin, OUTPUT);
  pinMode(shiftDigitClkPin, OUTPUT);
  pinMode(shiftDigitLatchPin, OUTPUT);

  pinMode(shiftSegDataPin, OUTPUT);
  pinMode(shiftSegClkPin, OUTPUT);
  pinMode(shiftSegLatchPin, OUTPUT);

  initDigits();
  initSegs();

  #if DEBUG
  Serial.begin(115200);
  #endif

  WiFi.mode(WIFI_STA);
  WiFi.begin(ssid, password);

  while (WiFi.waitForConnectResult() != WL_CONNECTED) {
    WiFiMulti.addAP(ssid, password);
    WiFi.begin(ssid, password);
    #if DEBUG
    Serial.println("Retrying connection...");
    #endif
  }
  #if OTA_ENABLED
  ArduinoOTA.setHostname(host);
  ArduinoOTA.onStart([]() { // switch off all Digits&Segments during upgrade
    initDigits();
    initSegs();
    digitData=B00000001;
    displayIdx=1;
  });
  ArduinoOTA.onEnd([]() { // do a fancy thing with our board led at end
    flashLEDBuiltIn();
  });

  ArduinoOTA.onError([](ota_error_t error) {
    (void)error;
    ESP.restart();
  });

  /* setup the OTA server */
  ArduinoOTA.begin();
  #endif
  #if DEBUG
  Serial.println("Ready");
  #endif

  flashLEDBuiltIn();

  //begin the clock on this steup and establish the time 
  configTime("CET-1CEST,M3.5.0,M10.5.0/3", "fritz.box",  "de.pool.ntp.org");
  delay(100);

  lastUpdate  = millis();
  cmd_server.begin(); //begin the wifi server 
}


void loop() {

  #if OTA_ENABLED
  ArduinoOTA.handle();
  #endif

  if (WiFi.status() == WL_CONNECTED){

    multiplexLoop(multiplexDelay);  //multiplex Digits, load current Segment values
    showWebInterface();
    getWeather();

    if (multiplexCount% 30 == 0) {
      time_t now = time(&now);
      localtime_r(&now, &tm);

      //update the time from the router or external server on the predefined time interval
      if ((millis()-lastUpdate) > (updateIntervallTime*oneMinuteinMillis)){
        configTime("CET-1CEST,M3.5.0,M10.5.0/3", "fritz.box",  "de.pool.ntp.org");
        lastUpdate = millis();
      }
      mainLoop(tm.tm_hour, tm.tm_min, tm.tm_sec); 
    } 
  } else { //if wifi is down dont update the time
    multiplexLoop(multiplexDelay);
    if (multiplexCount% 50 == 0) {  
      time_t now = time(&now);
      localtime_r(&now, &tm);
      mainLoop(tm.tm_hour, tm.tm_min, tm.tm_sec); 
    }
  }
}

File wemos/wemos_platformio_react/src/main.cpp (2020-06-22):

#include <ESP8266React.h>
#include <LightStateService.h>
//#include <FS.h>
#include <LittleFS.h>
#include <LEDScoreboardService.h>

#define SERIAL_BAUD_RATE 115200

AsyncWebServer server(80);
ESP8266React esp8266React(&server, &LittleFS);
LightStateService lightStateService = LightStateService(&server,
                                                        esp8266React.getSecurityManager());
LEDScoreboardService ledScoreboardService = LEDScoreboardService(&server,
                                                        esp8266React.getSecurityManager(),
                                                        esp8266React.getNTPStatus());
#define DEBUG false
void setup() {
  // start serial and filesystem
  #if DEBUG
  Serial.begin(SERIAL_BAUD_RATE);
  #endif
  // start the file system (must be done before starting the framework)
#ifdef ESP32
  LittleFS.begin(true);
#elif defined(ESP8266)
  LittleFS.begin();
#endif

  // start the framework and demo project
  esp8266React.begin();
  /*esp8266React.getNTPSettingsService()->addUpdateHandler(
    [&](const String& originId) {
      Serial.println("NTP updated");
    });
    }
  );*/

  // load the initial light settings
  lightStateService.begin();

  ledScoreboardService.begin();

  // start the server
  server.begin();
}

void loop() {
  // run the framework's loop function
  esp8266React.loop();
  ledScoreboardService.loop();
}

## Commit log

2020-06-02 Eagle Schematic added
    [score_anzeige.sch]
2020-06-02 Test Sketch für MAX7219 + Transistoren added
    [max7219_high_voltage.sch]
2020-06-04 Schematic fixed
2020-06-04 tschüüüüüs
    [max7219_high_voltage.sch]
2020-06-04 Test Schematic updated
    [max7219_high_voltage.sch]
2020-06-04 test 2k2Ohm ansatt 220
    [max7219_high_voltage.sch]
2020-06-05 update idea #1
    [#1.sch]
2020-06-06 ides/no1 Schematic
    [score_anzeige_register.sch]
2020-06-06 picture with cable pins
2020-06-06 update picture with cable pins
2020-06-07 1_route_1register.sch updated
    [#1.brd, #1.sch, #1_routed.brd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]
2020-06-08 1_route_1register.sch changed
    [#1_routed_1register.brd, #1_routed_1register.sch]
2020-06-11 Schematic updated + Refactoring
    [#1_routed_1register.brd, #1_routed_1register.sch, LEDAnzeige_Multiplexing.brd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]
2020-06-11 Board added
2020-06-11 Mirrored Boardimage for Soldering added
2020-06-12 Board updated
    [LEDAnzeige_Multiplexing.brd, LEDAnzeige_Multiplexing.sch]
2020-06-15 Added clock and temperature display
2020-06-16 added home and guest score board support
2020-06-20 LEDScoreboardService with wemos_sketch
2020-06-21 Add NTPStatus to LEDScoreboardService + default wemosLoop show current LocalTime test
2020-06-22 added comments and changed time to avoid flickering
    [modes.h, wemos_sketch.cpp]

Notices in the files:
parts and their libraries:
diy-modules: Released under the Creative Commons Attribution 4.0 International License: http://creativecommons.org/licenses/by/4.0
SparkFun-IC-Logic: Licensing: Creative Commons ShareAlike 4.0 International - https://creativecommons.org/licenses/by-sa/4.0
